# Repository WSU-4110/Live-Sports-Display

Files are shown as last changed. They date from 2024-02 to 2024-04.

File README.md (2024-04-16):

# Live-Sports-Display

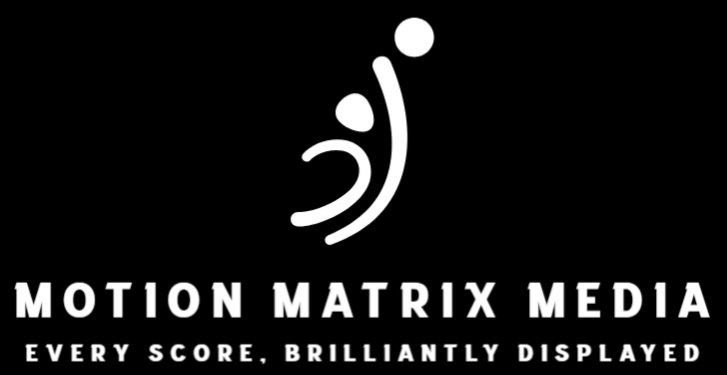
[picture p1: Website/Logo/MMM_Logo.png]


## Our Website
Our website can be accessed here:
https://livesportsdisplay-78ab65502a20.herokuapp.com/

## Our Purpose:
This project aims to display live Scores on an LED Matrix Panel.

## Our Team members:

- Timothy Kosinski 
- Najib Mohammad
- Jordan Grewe
- Ayman Elfayoumi
- Mitchel Brown
- Rory Jolliff

## How it works:
Our project has four main code sections:
- The Webserver connection
- Optical Character Recognition (OCR)
- Sports API data collection (API)
- Hardware

These four section work together to create our product:
- The webserver code connects the other portions, allowing for user input of images - and output of relevant information to the hardware
- The OCR code allows for images to be searched for both team and player names - sending them to the API code
- The API code allows for the collection of the data on the teams and players - sending it to the Hardware code
- The Hardware code takes the data it is given, and displays it to the user on an LED Matrix Panel

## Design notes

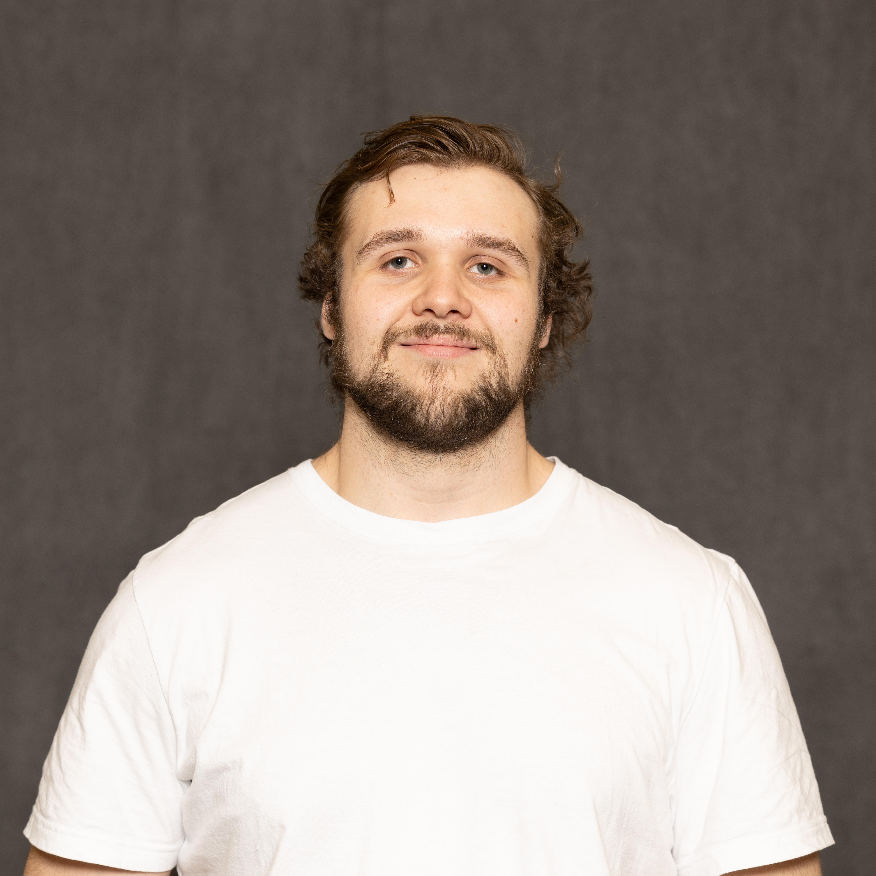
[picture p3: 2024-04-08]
Website/LiveStats/static/images/m_brown.jpg

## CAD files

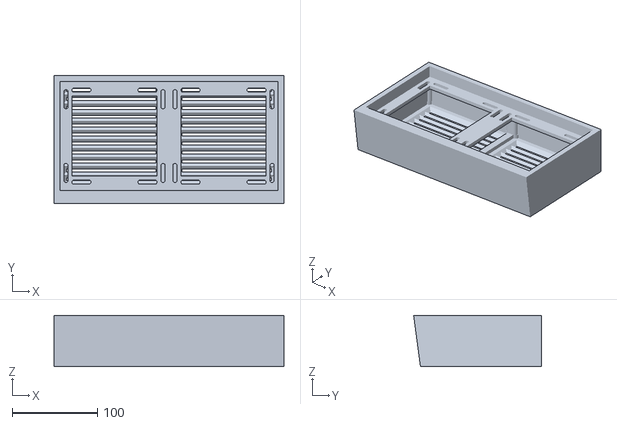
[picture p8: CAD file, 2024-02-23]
Hardware Documentation/Display Case LED 64x64/Version2/Complete Case - Version 2.stl
270.0 x 150.0 x 60.0

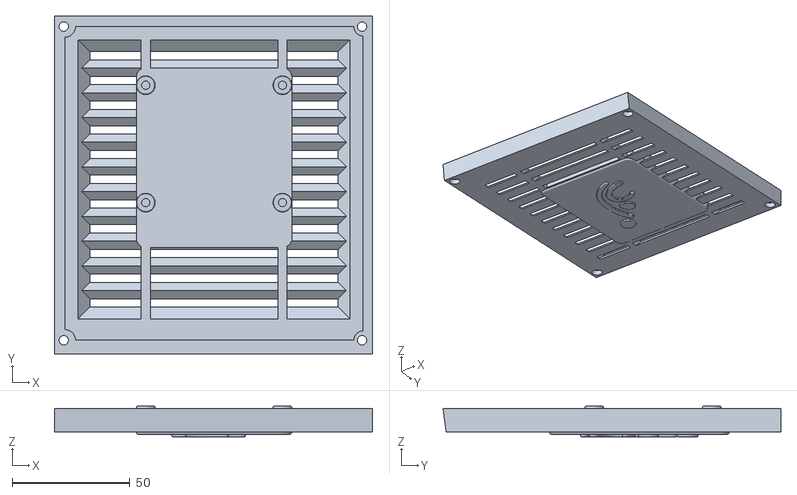
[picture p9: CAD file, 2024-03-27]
Hardware Documentation/64x128 LED Display Cad Files/Version 4/64x64 LED Display Cover - Left Side 16MAR2024.stl
135.0 x 143.3 x 13.0

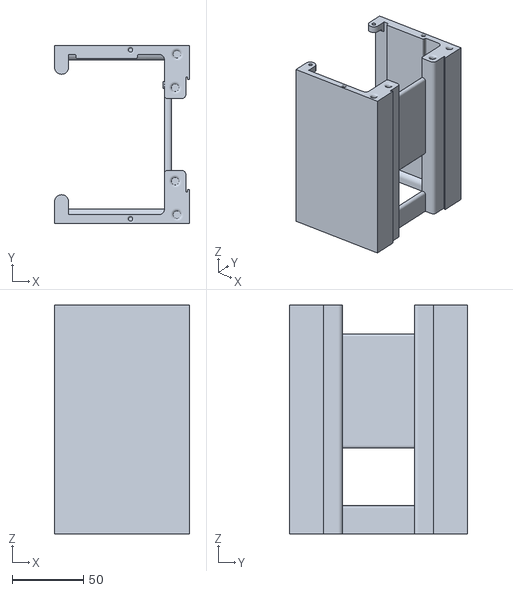
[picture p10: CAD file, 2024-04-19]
Hardware Documentation/8x96 LED Display Cad Files/Print 03APR2024/Cross Section 6 of 6 (03APR2024).stl
94.5 x 124.2 x 160.2

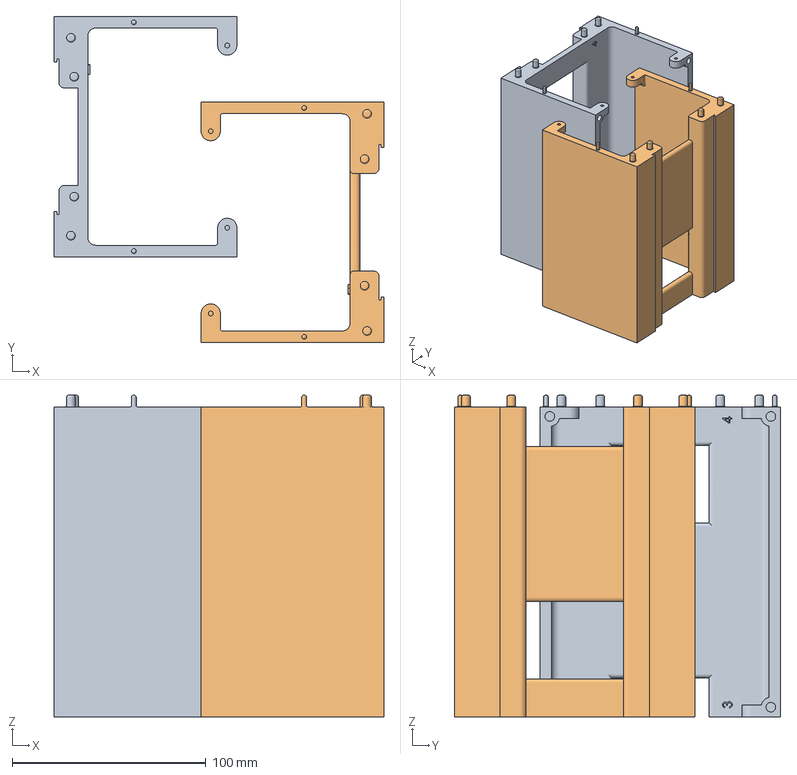
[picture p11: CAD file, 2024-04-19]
Hardware Documentation/8x96 LED Display Cad Files/Print 04APR2024/Cross Section 3 of 6 (03APR2024).3mf
170.5 x 168.5 x 166.2 mm
Cross Section 4 of 6 (03APR2024).stl
Cross Section 3 of 6 (03APR2024).stl

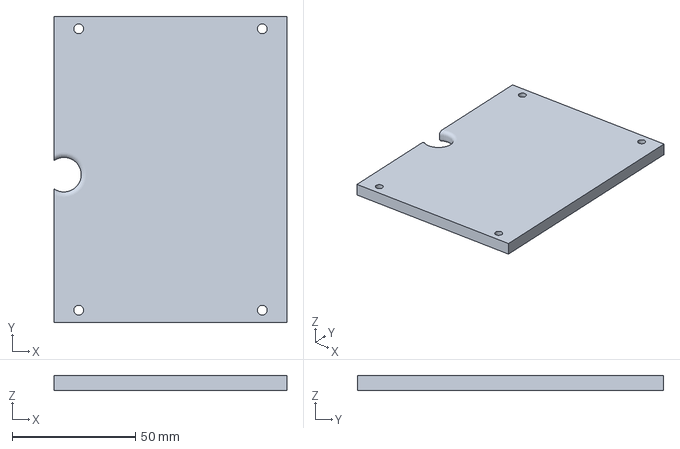
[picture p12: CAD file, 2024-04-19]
Hardware Documentation/8x96 LED Display Cad Files/Print 08APR2024/Right -Side Panel 08APR2024.3mf
94.5 x 124.2 x 6.00 mm

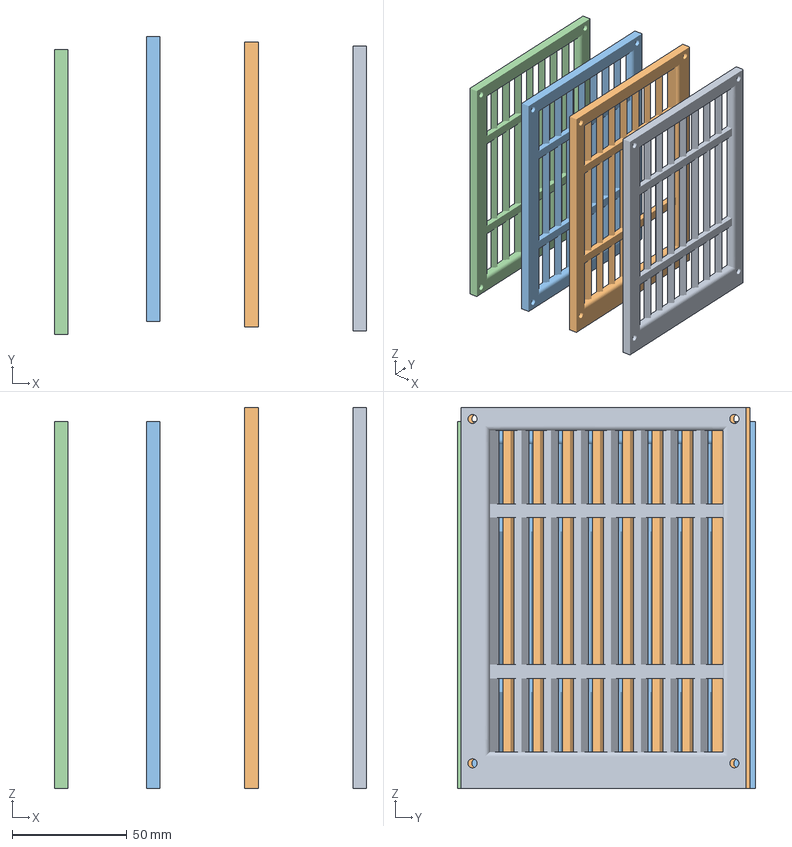
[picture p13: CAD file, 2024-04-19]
Hardware Documentation/8x96 LED Display Cad Files/Print 09APR2024/back panel -Right 09APR2024.3mf
136.2 x 129.9 x 166.2 mm
back panel -Left 09APR2024.stl
back panel -Right 09APR2024.stl
back panel 2-4 sections 09APR2024.stl x 2

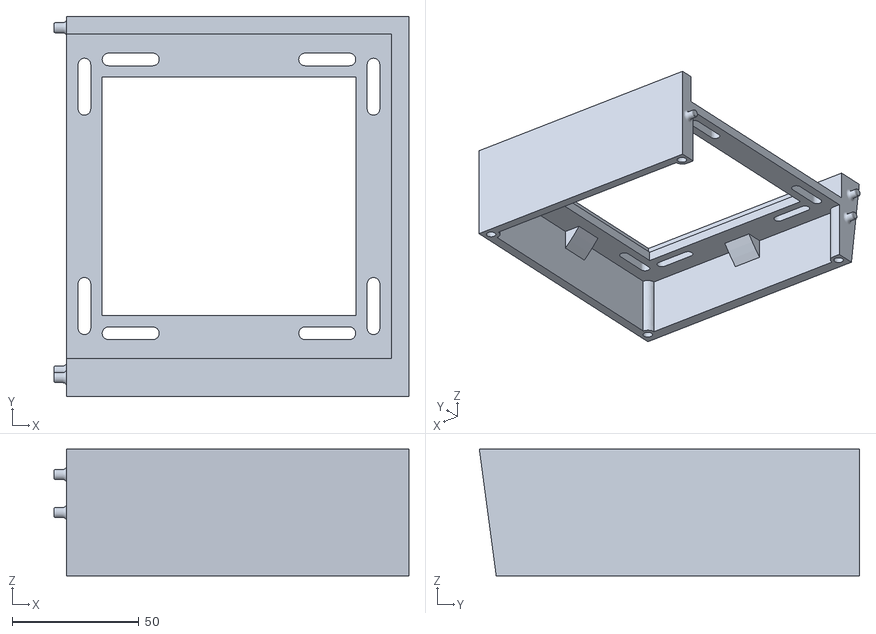
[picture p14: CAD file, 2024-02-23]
Hardware Documentation/Display Case LED 64x64/Version2/64x64 LED Display Case - Right Side (Test Print 3).stl
140.0 x 150.0 x 50.0

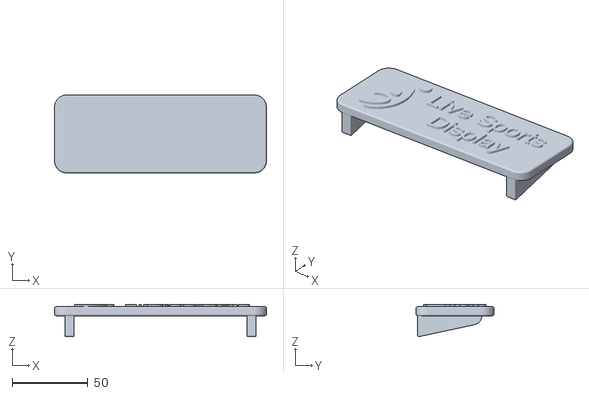
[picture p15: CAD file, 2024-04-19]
Logo and Name Tags/Name Tag V3 Title v0.stl
140.0 x 51.5 x 21.3

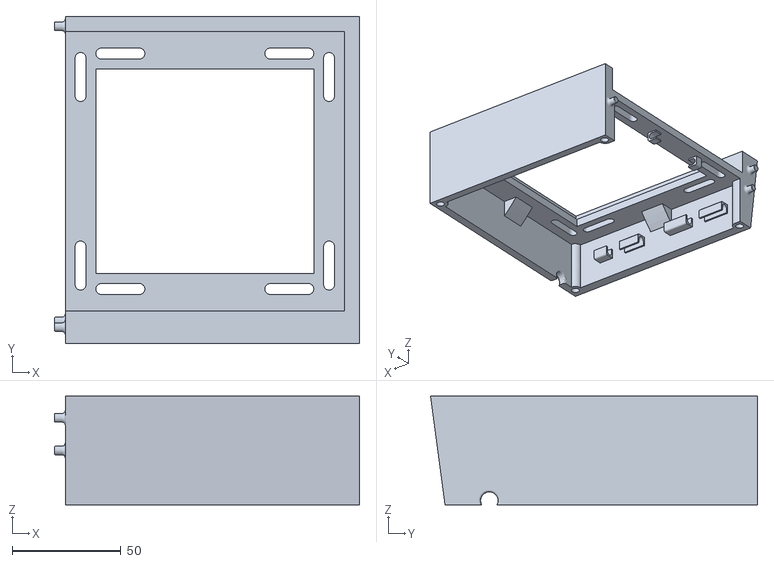
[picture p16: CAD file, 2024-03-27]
Hardware Documentation/64x128 LED Display Cad Files/Version 4/64x64 LED Display Case - Right Side 15MAR2024.stl
140.0 x 150.0 x 50.0

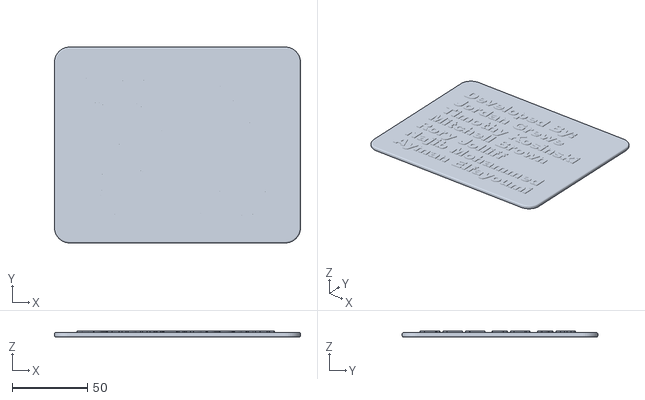
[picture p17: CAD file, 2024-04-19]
Hardware Documentation/8x96 LED Display Cad Files/Developed Plaque Names.stl
163.3 x 130.0 x 4.00

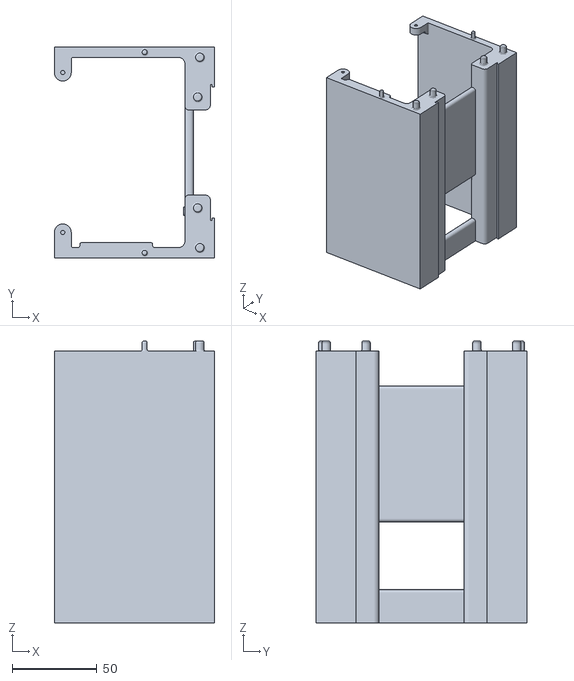
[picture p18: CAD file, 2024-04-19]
Hardware Documentation/8x96 LED Display Cad Files/Print 03APR2024/Cross Section 5 of 6 (03APR2024).stl
94.5 x 124.2 x 166.2

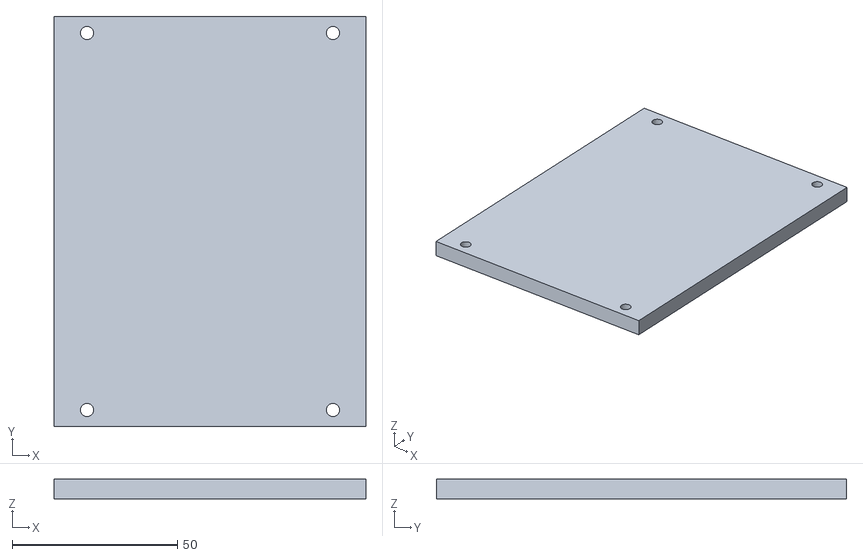
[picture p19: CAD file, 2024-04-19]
Hardware Documentation/8x96 LED Display Cad Files/Print 08APR2024/Left-Side Panel (08APR2024).stl
94.5 x 124.2 x 6.00

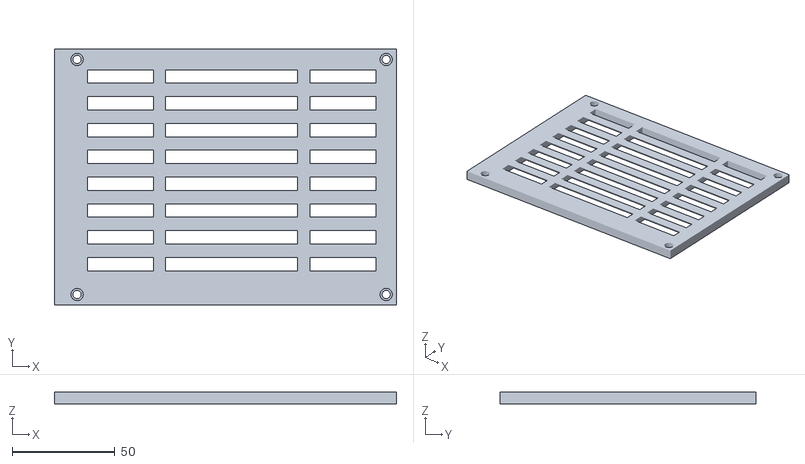
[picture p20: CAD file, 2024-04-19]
Hardware Documentation/8x96 LED Display Cad Files/Print 09APR2024/back panel -Left 09APR2024.stl
166.2 x 124.2 x 6.00

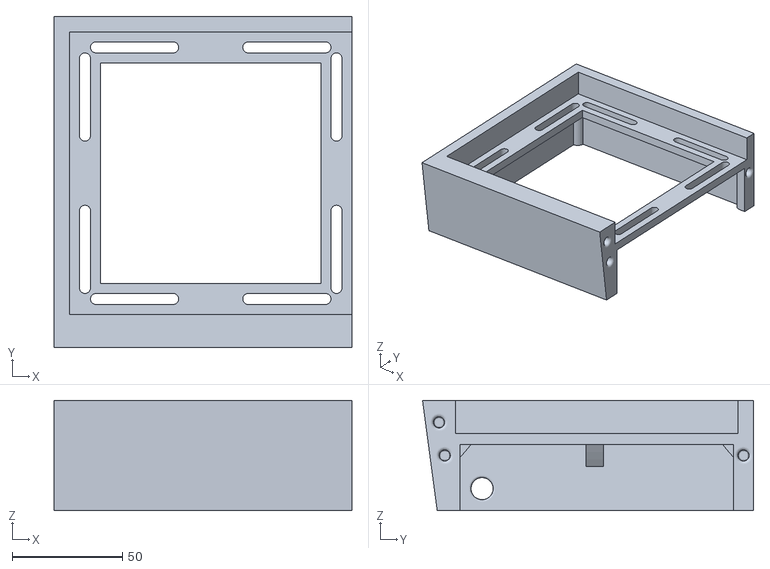
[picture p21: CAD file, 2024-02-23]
Hardware Documentation/Display Case LED 64x64/Version2/64x64 LED Display Case - Left Side V2.stl
135.0 x 150.0 x 50.0

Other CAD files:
Hardware Documentation/8x96 LED Display Cad Files/Print 04APR2024/Cross Section 4 of 6 (03APR2024).stl
Logo and Name Tags/Name Tags Timothy.stl
Hardware Documentation/64x128 LED Display Cad Files/Version 4/64x64 LED Display Cover - Left Side 22MAR2024.stl
Hardware Documentation/8x96 LED Display Cad Files/Print 04APR2024/Cross Section 2 of 6 (04APR2024).stl
Hardware Documentation/64x128 LED Display Cad Files/Version 4/64x64 LED Display Case - Left Side 15MAR2024.stl
Hardware Documentation/64x128 LED Display Cad Files/Version 4/64x64 LED Display Cover - Right Side 16MAR2024.stl
Hardware Documentation/8x96 LED Display Cad Files/Cross Section 1 of 6 (31MAR2024).stl
Hardware Documentation/8x96 LED Display Cad Files/Cross Section 2 of 6 (04APR2024).3mf
Hardware Documentation/8x96 LED Display Cad Files/Cross Section 2 of 6 (31MAR2024).3mf
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

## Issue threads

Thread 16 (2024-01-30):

FR10. Power, Wi-Fi connectivity

Grewestr, 2024-01-30:
|FR10. Power, Wi-Fi connectivity |
|---|
|**Goal**: The system will require the clients, providers, and server to have power (110V minimum) and connection to a Wi-Fi network.
**Stakeholders:** Clients, Providers |
| **Description:** All components of the project need to have ample power as well as strong Wi-Fi connection. The hardware requires a power supply that takes in 110 V (wall outlet) and converts it to 5V 20 A for both the microprocessor and the LED display. The processor needs Wi-Fi connection to our webserver to receive live data to display. |
| **Origin:** This idea came up with the original documentation regarding the flow chart described in the team project as a visual representation on how this program would function. |
| **Version:** 1.0 |
|**Date:** 01/29/2024
| **Priority:** 1 |

Closed 2024-02-11.

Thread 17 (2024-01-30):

FR11. Having the LED display

Grewestr, 2024-01-30:
|FR11. Having the LED display  |
|---|
|**Goal**: The Customers (sometimes referred to as clients) need to be in physical possession of the LED display in order to get results from website. |
**Stakeholders:** Clients |
| **Description:** The goal of this requirement is that the clients must possess and provide ample power to the display. This will require correct wiring to the 3 pins on the back of the display to provide ground, data, and power.  |
| **Origin:** This idea came up at our second meeting when discussing requirements regarding how the unit should be displayed. The LED displays arrived on 1/26/24 and we were able to determine the requirements from there. |
| **Version:** 1.0 |
|**Date:** 01/29/2024
| **Priority:** 1 |

Closed 2024-02-11.

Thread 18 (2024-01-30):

FR12. Booting Raspberry Pi with rpi imager as well as rpi Operating System

Grewestr, 2024-01-30:
|FR12. Booting Raspberry Pi with rpi imager as well as rpi Operating System  |
|---|
|**Goal**: Develop a framework on the microprocessor to control the LED display and connect to the webserver. |
|**Stakeholders:** Clients |
| **Description:** We will develop a framework on the microprocessor using an OS like Debian (Linux based) and then install a rpi imager to control the GUID pins on the processor. This will also allow us to retrieve live data from our Django based webserver. |
| **Origin:** This idea came up during our second meeting together, the hardware team determined how to use the microprocessor. |
| **Version:** 1.0 |
|**Date:** 01/29/2024
| **Priority:** 1 |

Closed 2024-02-01.

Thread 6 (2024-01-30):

FR5. Identifying IP Address Connected to Hardware

MitchellBrownNE, 2024-01-30:
|FR5. Identifying IP Address Connected to Hardware|
|---|
|**Goal**: The system will be able to identify the IP address connected to the hardware without issues.|
**Stakeholders:** Clients, Providers|
| **Description:** The system should be able to flawlessly detect what the IP address of the hardware that is currently connected to it. If the system is obtaining an incorrect IP address, it should display a message that the hardware has not been detected. The system will be able to display the connected hardware and be able to communicate with it. The system should allow devices to be detected for a minute and report information in 3 seconds.|
| **Origin:** Based on initial project specification document, team members came up with this description during the second meeting.|
| **Version:** 1.0 |
|**Date:** 01/28/2024
| **Priority:** 5 |

TKosinski24, 2024-04-04:
Used PiTunnel to create a custom IP tunnel to identify specific R PI units

Closed 2024-04-04.

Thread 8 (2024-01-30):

FR7. Hardware Networking Function General

TKosinski24, 2024-01-30:
| FR7.  Hardware networking function general  |
| ------------- |
| **Goal:** The system will connect to the server and receive user data|
| **Stakeholders:** Clients, Providers |
| **Description:** When connecting all components, (Raspberry Pi, display, and power supply) the unit will be able to connect to the webserver and receive data from the requested sources. This information is used to display Users' sports data onto the display. |
| **Origin:** This idea came up with the original documentation regarding the flow chart described in the team project as a visual representation on how this program would function.  |
| **Version:** 1.0 |
| **Date:** 01/28/2024 |
| **Priority:** 1 |

TKosinski24, 2024-04-04:
Using SSH to connect to the Raspberry Pi to run scripts that drive the LED Matrix Panels. (PiTunnel)

TKosinski24, 2024-04-04:
Using SSH to remote into the Raspberry PI that uses a secure connection created by PiTunnel, then calls Sports API to retrieve user data.

Closed 2024-04-04.

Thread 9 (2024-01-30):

NFR2. Case For Hardware Display 2 ( LED 64x128 )

TKosinski24, 2024-01-30:
| NFR2.  Case for Hardware |
| ------------- |
| **Goal:** The system will be contained within a case that can easily hold all functional hardware components|
| **Stakeholders:** Clients, Providers |
| **Description:** When all components are connected to become one solo unit, a case will be provided to hold all essential items in one case. This would make it easier and provide a clean and concise look for the end result. |
| **Origin:** This idea came up at our second meeting when discussing requirements regarding how the unit should be displayed. This is a nonfunctional requirement but should be a part of the final product.   |
| **Version:** 1.0 |
| **Date:** 01/28/2024 |
| **Priority:** 2 |

TKosinski24, 2024-03-27:
Version 5 of the CAD Case is finished and no modifications need to be done

Closed 2024-03-27.

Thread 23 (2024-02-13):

NFR8 Case For Hardware Display 1 (LED 8x96)

Grewestr, 2024-02-13:
### Goal

Design and 3D model a case for the 8x36 inch display

### Description

Use CAD software like Fusion 360 or SolidWorks to create a case that houses the power supply, Raspberry Pi, 3 LED panels and Wiring for the design. The goal is to make the "Rpi" modular so it can be taken out of the display for easy configuration.

### Stakeholders

Clients, Providers

### Date

2/13/24

### Version

1.0

### Origin

Lab 2/13/24 - discussion with Tim

### Priority of the proposed feature

Should have

Grewestr, 2024-03-26:
Completed tims case

Closed 2024-03-26.

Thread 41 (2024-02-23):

FR 19 Client informs webserver the display name

Grewestr, 2024-02-23:
### Goal

For display

### Description

When a client uploads/chooses the player data to display , the client will also pick a display name that is attached to their data. (html var upload)

### Stakeholders

Clients, Providers

### Date

_No response_

### Version

_No response_

### Origin

2/23 meeting

### Priority of the proposed feature

None

Grewestr, 2024-03-26:
buttons on result page

Closed 2024-03-26.

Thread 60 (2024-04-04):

[NFR-9] HomeScreen 64x128 LED Matrix

TKosinski24, 2024-04-04:
### Goal

Displaying a Home Screen

### Description

On boot up, the LED 64x128Matrix will display a home screen with the project logo before booting to its next state.

### Stakeholders

General Users

### Date

04APR2024

### Version

1

### Origin

Group Meeting

### Priority of the proposed feature

Could have

TKosinski24, 2024-04-06:
Done, the display loads with the project logo and uses that time to call any player's name that requires an API. then either Loading... No Stats... or Error... depending on the situation

Accepting:
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

Non-NBA Player Name:
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

NBA player that hasn't played yet:
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

Closed 2024-04-06.

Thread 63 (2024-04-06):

[BUG] LED 128x64 Display - Printing Layout

TKosinski24, 2024-04-06:
### Is there an existing issue for this?

- [X] I have searched the existing issues

### Current Behavior

When printing the User layout, Some players with no data are still being printed.

### Expected Behavior

When printing user layout. Players with no data are not supposed to be printed, even blank spaces

### Steps To Reproduce

1. enter player names into Players.txt.
2. run program.
3. Deandre Ayton, Jabari Walker, Deni Audji, Player 1, Tre Mann, Gary Harris, Jimmy Butler, Jalen Green

Terminal Output:
Updating stats for: Deandre Ayton
Updating stats for: Jabari Walker
Updating stats for: Deni Avdija
No stats found for Random
Updating stats for: Tre Mann
Updating stats for: Gary Harris
Updating stats for: Jimmy Butler
Updating stats for: Jalen Green
No stats found for Michael Jordan

### Environment

```markdown
- OS: Raspbian OS
- Node: N/A
- npm: N/A
- Program Lang.: Python
```

### Anything else?

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

TKosinski24, 2024-04-06:
Had to adjust the for loop responsible for determining if the players with "default" values would be skipped if present. this fixed this formatting issue and now prints as intended.

File Input:
Deandre Ayton,Jabari Walker,Deni Avdija,Random,Tre Mann,Gary Harris,Jimmy Butler,Jalen Green,Michael Jordan

Terminal Output:
Updating stats for: Deandre Ayton
Updating stats for: Jabari Walker
Updating stats for: Deni Avdija
No stats found for Random
Updating stats for: Tre Mann
Updating stats for: Gary Harris
Updating stats for: Jimmy Butler
Updating stats for: Jalen Green
No stats found for Michael Jordan

Image Example:

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

Closed 2024-04-06.

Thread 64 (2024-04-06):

[BUG] LED 128x64 Formatting Player Stats

TKosinski24, 2024-04-06:
### Is there an existing issue for this?

- [X] I have searched the existing issues

### Current Behavior

When printing player stats, it prints as "one" string and doesn't look seamless. So there are usually large gaps in the display when this happens.

### Expected Behavior

When printing player stats, stats should be seamless with no more than 26px in between each text.

### Steps To Reproduce

1.upload players in players.txt.
2. run program
3. wait for printing on display to happen.

### Environment

```markdown
- OS: Raspbian OS
- Programming Lang: Python
```

### Anything else?

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

TKosinski24, 2024-04-06:
Fixed issue. instead of an "awkward pause", there is an instant print of the player stats as soon as it's no longer in the user's view.

Closed 2024-04-06.

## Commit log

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2024-02-15 Rename M4x10x6mm Brass Insert Test Block - Version 1.stl to Display Case LED 64x64/M4x10x6mm Brass Insert Test Block - Version 1.stl
    [M4x10x6mm Brass Insert Test Block - Version 1.stl]
2024-02-15 Rename 64x64 LED Display Case - Left Side - Version 2.stl to Display Case LED 64x64/64x64 LED Display Case - Left Side - Version 2.stl
    [64x64 LED Display Case - Left Side - Version 2.stl]
2024-02-15 Rename 64x64 LED Display Case - Left Side V2.stl to Display Case LED 64x64/64x64 LED Display Case - Left Side V2.stl
    [64x64 LED Display Case - Left Side V2.stl]
2024-02-15 Rename 64x64 LED Display Case - Right Side (Test Print 3).stl to Display Case LED 64x64/64x64 LED Display Case - Right Side (Test Print 3).stl
    [64x64 LED Display Case - Right Side (Test Print 3).stl]
2024-02-15 Rename 64x64 LED Display Case - Right Side - Version 2.stl to Display Case LED 64x64/64x64 LED Display Case - Right Side - Version 2.stl
    [64x64 LED Display Case - Right Side - Version 2.stl]
2024-02-15 Rename 64x64 LED Display Cover - Left Side - Version 1.stl to Display Case LED 64x64/64x64 LED Display Cover - Left Side - Version 1.stl
    [64x64 LED Display Cover - Left Side - Version 1.stl]
2024-02-15 Rename 64x64 LED Display Cover - Right Side - Version 1.stl to Display Case LED 64x64/64x64 LED Display Cover - Right Side - Version 1.stl
    [64x64 LED Display Cover - Right Side - Version 1.stl]
2024-02-15 Rename Complete Case - Version 2.stl to Display Case LED 64x64/Complete Case - Version 2.stl
    [Complete Case - Version 2.stl]
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2024-02-15 Rename Display Case LED 64x64/M4x10x6mm Brass Insert Test Block - Version 1.stl to Display Case LED 64x64/Version1/M4x10x6mm Brass Insert Test Block - Version 1.stl
    [M4x10x6mm Brass Insert Test Block - Version 1.stl]
2024-02-15 Rename Display Case LED 64x64/64x64 LED Display Cover - Right Side - Version 1.stl to Display Case LED 64x64/Version1/64x64 LED Display Cover - Right Side - Version 1.stl
    [64x64 LED Display Cover - Right Side - Version 1.stl]
2024-02-15 Rename Display Case LED 64x64/64x64 LED Display Cover - Left Side - Version 1.stl to Display Case LED 64x64/Version1/64x64 LED Display Cover - Left Side - Version 1.stl
    [64x64 LED Display Cover - Left Side - Version 1.stl]
2024-02-15 Rename Display Case LED 64x64/64x64 LED Display Case - Left Side - Version 2.stl to Display Case LED 64x64/Version2/64x64 LED Display Case - Left Side - Version 2.stl
    [64x64 LED Display Case - Left Side - Version 2.stl]
2024-02-15 Rename Display Case LED 64x64/64x64 LED Display Case - Left Side V2.stl to Display Case LED 64x64/Version2/64x64 LED Display Case - Left Side V2.stl
    [64x64 LED Display Case - Left Side V2.stl]
2024-02-15 Rename Display Case LED 64x64/64x64 LED Display Case - Right Side (Test Print 3).stl to Display Case LED 64x64/Version2/64x64 LED Display Case - Right Side (Test Print 3).stl
    [64x64 LED Display Case - Right Side (Test Print 3).stl]
2024-02-15 Rename Display Case LED 64x64/64x64 LED Display Case - Right Side - Version 2.stl to Display Case LED 64x64/Version1/64x64 LED Display Case - Right Side - Version 1.stl
    [64x64 LED Display Case - Right Side - Version 1.stl]
2024-02-15 Rename Display Case LED 64x64/Complete Case - Version 2.stl to Display Case LED 64x64/Version2/Complete Case - Version 2.stl
    [Complete Case - Version 2.stl]
2024-02-15 Delete 64x64 LED Display Case - Right Side (Test Print 3).stl
    Don't need, Pushed to Dev. Branch
    [64x64 LED Display Case - Right Side (Test Print 3).stl]
2024-02-15 Delete M4x10x6mm Brass Insert Test Block - Version 1.stl
    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
    [M4x10x6mm Brass Insert Test Block - Version 1.stl]
2024-02-15 Delete 64x64 LED Display Case - Left Side - Version 2.stl
    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
    [64x64 LED Display Case - Left Side - Version 2.stl]
2024-02-15 Delete 64x64 LED Display Case - Left Side V2.stl
    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
    [64x64 LED Display Case - Left Side V2.stl]
2024-02-15 Delete 64x64 LED Display Case - Right Side - Version 2.stl
    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
    [64x64 LED Display Case - Right Side - Version 2.stl]
2024-02-15 Delete 64x64 LED Display Cover - Left Side - Version 1.stl
    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
    [64x64 LED Display Cover - Left Side - Version 1.stl]
2024-02-15 Delete 64x64 LED Display Cover - Right Side - Version 1.stl
    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
    [64x64 LED Display Cover - Right Side - Version 1.stl]
2024-02-15 Delete Complete Case - Version 2.stl
    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
    [Complete Case - Version 2.stl]
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2024-03-17 Add files via upload
    This is the 4th version of the print with support to house the R Pi, and additional cable supports
    [64x64 LED Display Case - Left Side 15MAR2024.stl, 64x64 LED Display Case - Right Side 15MAR2024.stl, 64x64 LED Display Cover - Left Side 16MAR2024.stl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]
2024-03-17 Rename 64x64 LED Display Case - Left Side 15MAR2024.stl to Version 4/64x64 LED Display Case - Left Side 15MAR2024.stl
    [64x64 LED Display Case - Left Side 15MAR2024.stl]
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2024-03-23 Fixed files
    [64x64 LED Display Case - Left Side - Version 2.stl, 64x64 LED Display Case - Left Side V2.stl, 64x64 LED Display Case - Right Side (Test Print 3).stl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]
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2024-04-03 All calls require only team name or player name and had fixed jersey bug
    [2023_nba_roster.csv]
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2024-04-03 Revert "Merge Completed API_Calls with csv files."
    [2023_nba_roster.csv, 2023_season_schedule.csv, 64x64 LED Display Case - Left Side - Version 2.stl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]
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2024-04-04 Add files via upload
    CAD files for one through 6 cross sections for hardware Case. this doesn't include the side panels or the back panels
    [Cross Section 1 of 6 (04APR2024).stl, Cross Section 1 of 6 (31MAR2024).stl, Cross Section 2 of 6 (04APR2024).stl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]
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2024-04-04 Delete CAD Files 8x96 LED Display directory
    Will add files later, currently having problems pulling to repository
    [Cross Section 1 of 6 (31MAR2024).stl, Cross Section 2 of 6 (04APR2024).stl, Cross Section 2 of 6 (31MAR2024).3mf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]
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2024-04-06 Fixing bug that was Resolved in issues regarding "Printing Format"
2024-04-07 Typo fix
    Fixed a typo: 'boarder' to 'border'
2024-04-08 Update first.css
    Added some additional components that were missing (main & .button)
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2024-04-13 Attempting to fix location of message
    Message about image type is on the left side, attempting to center it below the button.
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2024-04-14 Attempting to Change Button Color
    Button Colors do not match Home Page. Attempting to fix in order to make page consistent.
2024-04-14 Button Change
    Attempting to Change Button font color, previous commit worked however words were now indistinguishable from background. Attempting to fix.
2024-04-14 Format Fix
    Attempting to fix and remove instructions that are in a bubble. This makes it look like a button which can be confusing for the user.
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2024-04-15 Updated Add Name Button
    Attempting to fix Add Name Button. Border is discolored.
2024-04-15 fixed roster
    [2023_nba_roster.csv]
2024-04-15 Re-Attempt at Fixing Button Style
    Trying Again to change button color
2024-04-15 Close Button Fix
    Fixing the close button colors now.
2024-04-15 Re-Attempt at Button Color Fix
    Add Player Name and Player Names Button colors should be fixed now.
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
